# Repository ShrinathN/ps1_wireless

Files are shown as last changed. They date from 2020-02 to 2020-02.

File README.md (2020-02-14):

# Project to turn any original PS1 or PS2 controller wireless using an AVR and a NRF24L01/NRF24L01+ radio

## Hardware

* atmega8a
* NRF24L01+ / NRF24L01
* PS1 / PS2 controller
* 18650 + TP4056 (I'm using an 18650, but you can choose whatever you want)

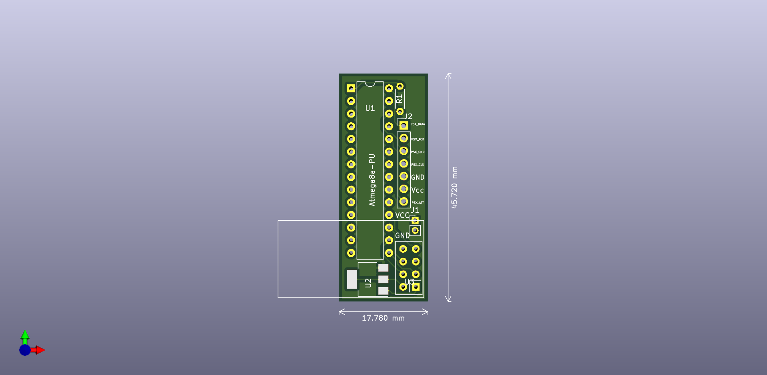
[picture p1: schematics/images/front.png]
Front Image


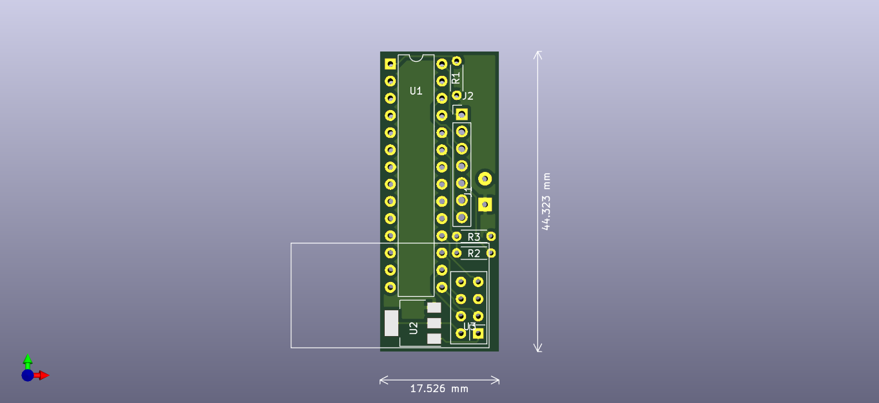
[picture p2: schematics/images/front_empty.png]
Front empty Image


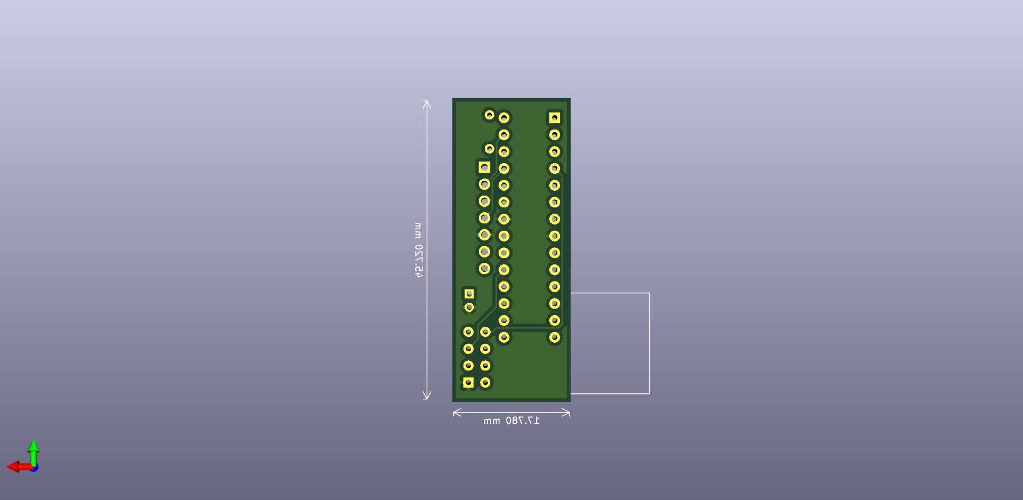
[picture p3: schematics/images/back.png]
Back Image


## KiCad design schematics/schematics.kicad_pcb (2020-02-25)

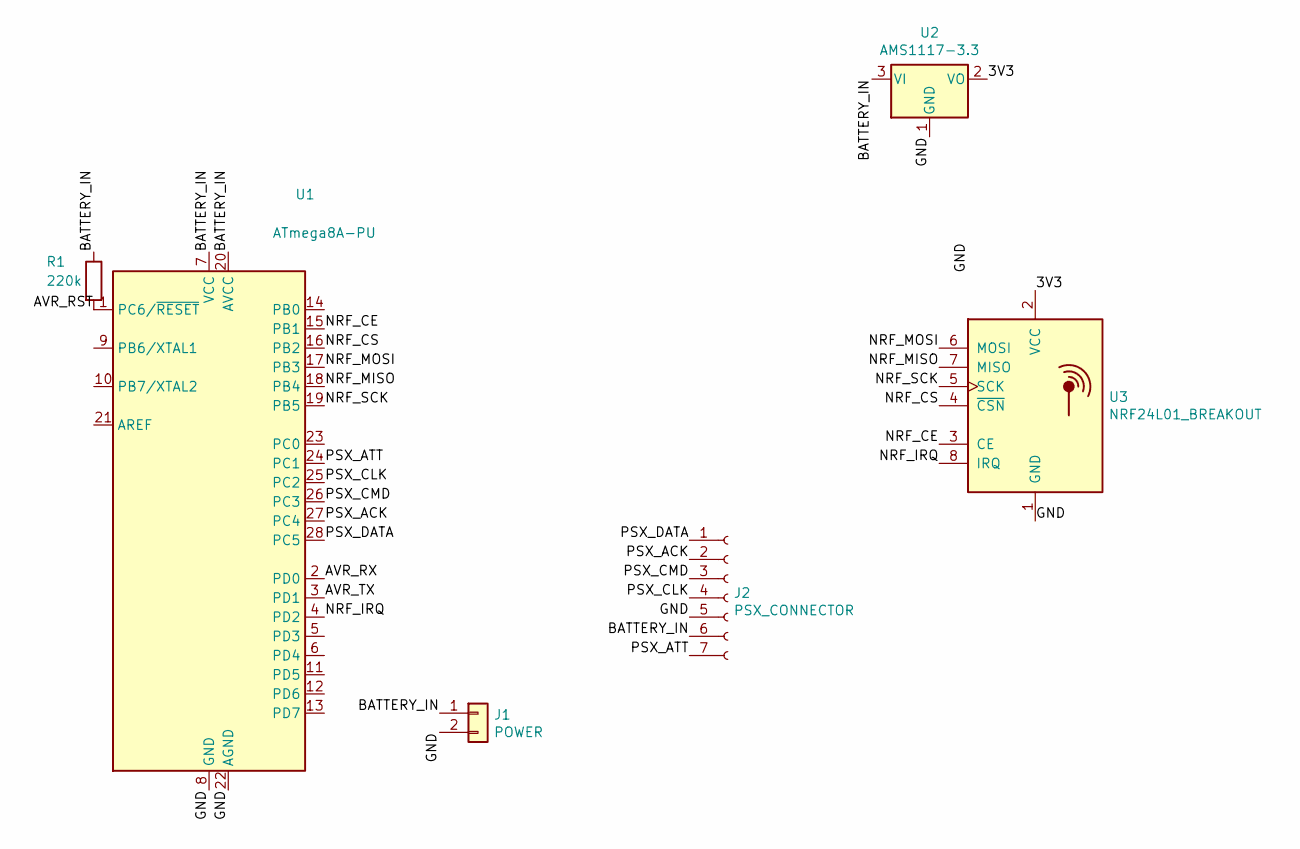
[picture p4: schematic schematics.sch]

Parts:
J1: POWER; PinHeader_1x02_P2.00mm_Vertical
J2: PSX_CONNECTOR; PinHeader_1x07_P2.54mm_Vertical
R1: 220k; R_Axial_DIN0204_L3.6mm_D1.6mm_P5.08mm_Horizontal
U1: ATmega8A-PU; DIP-28_W7.62mm
U2: AMS1117-3.3; SOT-223-3_TabPin2
U3: NRF24L01_BREAKOUT; nRF24L01_Breakout

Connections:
/3V3: U2.2 (VO), U3.2 (VCC)
/AVR_RST: R1.2, U1.1 (PC6/~RESET)
/AVR_RX: U1.2 (PD0)
/AVR_TX: U1.3 (PD1)
/BATTERY_IN: J1.1, J2.6, R1.1, U1.7 (VCC), U1.20 (AVCC), U2.3 (VI)
/GND: J1.2, J2.5, U1.8 (GND), U1.22 (AGND), U2.1 (GND), U3.1 (GND)
/NRF_CE: U1.15 (PB1), U3.3 (CE)
/NRF_CS: U1.16 (PB2), U3.4 (~CSN)
/NRF_IRQ: U1.4 (PD2), U3.8 (IRQ)
/NRF_MISO: U1.18 (PB4), U3.7 (MISO)
/NRF_MOSI: U1.17 (PB3), U3.6 (MOSI)
/NRF_SCK: U1.19 (PB5), U3.5 (SCK)
/PSX_ACK: J2.2, U1.27 (PC4)
/PSX_ATT: J2.7, U1.24 (PC1)
/PSX_CLK: J2.4, U1.25 (PC2)
/PSX_CMD: J2.3, U1.26 (PC3)
/PSX_DATA: J2.1, U1.28 (PC5)

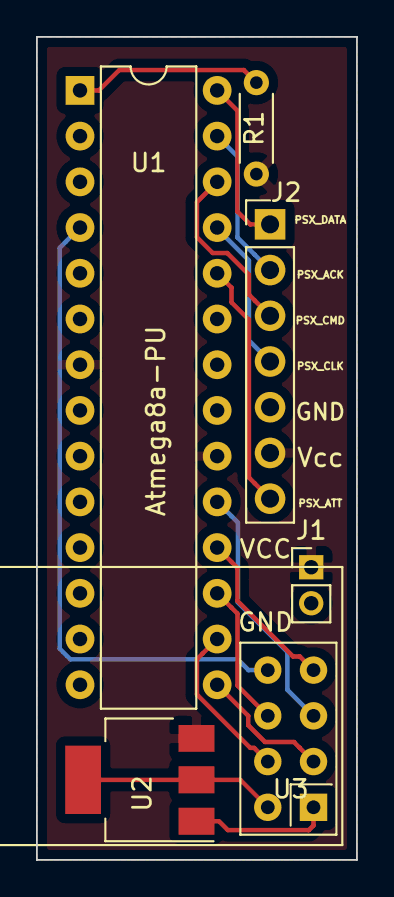
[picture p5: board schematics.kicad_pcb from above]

Board: 2 copper layers, 17.8 x 45.7 mm, 6 parts (0 on the bottom side), 15 nets.

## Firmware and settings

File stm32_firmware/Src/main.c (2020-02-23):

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

/* Includes ------------------------------------------------------------------*/
#include "main.h"
#include "usb_device.h"

/* USER CODE BEGIN Includes */
#include "NRF24L01.h"
/* USER CODE END Includes */

/* USER CODE BEGIN PTD */
extern USBD_HandleTypeDef hUsbDeviceFS;
/* USER CODE END PTD */

/* USER CODE BEGIN PM */
#define LED_OFF HAL_GPIO_WritePin(STATUS_LED_GPIO_Port, STATUS_LED_Pin, GPIO_PIN_SET)
#define LED_ON HAL_GPIO_WritePin(STATUS_LED_GPIO_Port, STATUS_LED_Pin, GPIO_PIN_RESET)
#define LED_TOGGLE HAL_GPIO_TogglePin(STATUS_LED_GPIO_Port, STATUS_LED_Pin)
#define CE_HIGH HAL_GPIO_WritePin(NRF_CE_GPIO_Port, NRF_CE_Pin, GPIO_PIN_SET)
#define CE_LOW HAL_GPIO_WritePin(NRF_CE_GPIO_Port, NRF_CE_Pin, GPIO_PIN_RESET)
/* USER CODE END PM */

SPI_HandleTypeDef hspi1;

void SystemClock_Config(void);
static void MX_GPIO_Init(void);
static void MX_SPI1_Init(void);
/* USER CODE BEGIN 0 */
/*
uint8_t USBD_HID_SendReport(USBD_HandleTypeDef  *pdev,
                            uint8_t *report,
                            uint16_t len)
*/
/* USER CODE END 0 */

/**
  * @brief  The application entry point.
  * @retval int
  */
int main(void)
{
  /* MCU Configuration--------------------------------------------------------*/

  /* Reset of all peripherals, Initializes the Flash interface and the Systick. */
  HAL_Init();

  /* Configure the system clock */
  SystemClock_Config();

  /* Initialize all configured peripherals */
  MX_GPIO_Init();
  MX_SPI1_Init();
  MX_USB_DEVICE_Init();
  /* USER CODE BEGIN 2 */
  HAL_Delay(1000);

  NRF_Init();
  NRF_SetAddressRx((BYTE[]){0x12,0x23,0x34}, 3, 0);
  NRF_WriteRegister(0x11, 3);
  NRF_SetMode(CONFIG_PWR_UP_UP);

  CE_HIGH;
  HAL_Delay(1);

  static BYTE buffer[3];
  BYTE a;
  BYTE b;
  /* USER CODE END 2 */



  /* Infinite loop */
  /* USER CODE BEGIN WHILE */
  while (1)
  {
    /* USER CODE END WHILE */
    /* USER CODE BEGIN 3 */
    while(HAL_GPIO_ReadPin(GPIOA, GPIO_PIN_0) == 1);
    a = NRF_ReadRegister(REG_STATUS);
    NRF_ReadRxFIFO(buffer, 3);
    NRF_WriteRegister(REG_STATUS, 0b01111111 & a);
    buffer[0] ^= 0xff;
    buffer[1] ^= 0xff;

    USBD_HID_SendReport(&hUsbDeviceFS, buffer, 2);
    LED_TOGGLE;
    /* USER CODE END WHILE */

    /* USER CODE BEGIN 3 */
  }
  /* USER CODE END 3 */
}

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


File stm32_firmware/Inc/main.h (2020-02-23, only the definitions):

#define STATUS_LED_Pin GPIO_PIN_13
#define STATUS_LED_GPIO_Port GPIOC
#define NRF_IRQ_Pin GPIO_PIN_0
#define NRF_IRQ_GPIO_Port GPIOA
#define NRF_CSN_Pin GPIO_PIN_3
#define NRF_CSN_GPIO_Port GPIOA
#define NRF_CE_Pin GPIO_PIN_4
#define NRF_CE_GPIO_Port GPIOA
#define NRF_SPI_SCK_Pin GPIO_PIN_5
#define NRF_SPI_SCK_GPIO_Port GPIOA
#define NRF_SPI_MISO_Pin GPIO_PIN_6
#define NRF_SPI_MISO_GPIO_Port GPIOA
#define NRF_SPI_MOSI_Pin GPIO_PIN_7
#define NRF_SPI_MOSI_GPIO_Port GPIOA

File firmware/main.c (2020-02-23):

#include "main.h"

void uart_init()
{
	UCSRB |= (1 << TXEN);
	UCSRC |= (1 << URSEL) |     //selecting UCSRC (NOT UBRRH)
	    (1 << UCSZ0) |      //setting as 8 bits
	    (1 << UCSZ1);
	UBRRL = 103;
}

void uart_send(uint8_t data)
{
	while(!(UCSRA & (1 << UDRE)));
	UDR = data;
}

static const uint8_t psx_poll_request[5] = {0x01,0x42,0,0,0};
static uint8_t recieve_block[5];
static uint8_t old_data[3]; //this is the data being sent
//old_data[0] and old_data[1] are PSX bytes
//old_data[2] is the percentage
static uint16_t loop_run_count;

void main()
{
	DDRB |= 1;
	PORTB &= ~(1);
	uart_init();
	BATTERY_AdcInit();
	PSX_PinsInit();

	//comm system init
	SPI_Init();
	_delay_ms(100);
	NRF_Init();

	NRF_SetAddressTx((uint8_t[]){0x12,0x23,0x34}, 3);
	NRF_SetMode(CONFIG_PWR_UP_UP);
	_delay_ms(2);

	loop_run_count = 0;
	// uart_send(NRF_ReadRegister(REG_CONFIG));
	while(1)
	{
		PSX_TransRecieveBlock((uint8_t *)psx_poll_request, recieve_block, 5);
		if((recieve_block[3] != old_data[0]) || (recieve_block[4] != old_data[1]))
		{
			// PORTB |= 1;
			old_data[0] = recieve_block[3];
			old_data[1] = recieve_block[4];
			NRF_FlushTxBuffer();
			NRF_WriteTxFIFO(old_data, 3);
			// uart_send(NRF_ReadRegister(REG_STATUS));
			// uart_send(NRF_ReadRegister(REG_FIFO_STATUS));
			NRF_Execute();
			NRF_IRQ_WAIT;
			// _delay_ms(10);
			// uart_send(NRF_ReadRegister(REG_STATUS));
			// uart_send(NRF_ReadRegister(REG_FIFO_STATUS));
			//clearing status
			NRF_WriteRegister(REG_STATUS, NRF_ReadRegister(REG_STATUS)  & 0b01111111);
			// _delay_ms(10);
			// PORTB &= ~1;
		}
		if(loop_run_count++ == BATTERY_SAMPLE_TIMER_THRESHOLD)
		{
			loop_run_count = 0;
			old_data[2] = BATTERY_GetPercentage();
		}
	}
}

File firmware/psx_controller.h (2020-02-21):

#ifndef PSX_CONTROLLER_H
#define PSX_CONTROLLER_H
#include "main.h"

//constants
#define PSX_DELAY_CLK_US 10
#define PSX_ATT_DELAY_US 20
#define PSX_INTER_BYTE_DELAY_US 20

//pin definitions
#define PSX_ATT_DDR DDRC
#define PSX_ATT_PORT PORTC
#define PSX_ATT_BIT PC1

#define PSX_CLK_DDR DDRC
#define PSX_CLK_PORT PORTC
#define PSX_CLK_BIT PC2

#define PSX_CMD_DDR DDRC
#define PSX_CMD_PORT PORTC
#define PSX_CMD_BIT PC3

#define PSX_ACK_DDR DDRC
#define PSX_ACK_PORT PORTC
#define PSX_ACK_PIN PINC
#define PSX_ACK_BIT PC4

#define PSX_DATA_DDR DDRC
#define PSX_DATA_PORT PORTC
#define PSX_DATA_PIN PINC
#define PSX_DATA_BIT PC5

//MACROS
#define PSX_CLK_LOW PSX_CLK_PORT &= ~(1 << PSX_CLK_BIT)
#define PSX_CLK_HIGH PSX_CLK_PORT |= (1 << PSX_CLK_BIT)
#define PSX_ATT_LOW PSX_ATT_PORT &= ~(1 << PSX_ATT_BIT)
#define PSX_ATT_HIGH PSX_ATT_PORT |= (1 << PSX_ATT_BIT)
#define PSX_CMD_LOW PSX_CMD_PORT &= ~(1 << PSX_CMD_BIT)
#define PSX_CMD_HIGH PSX_CMD_PORT |= (1 << PSX_CMD_BIT)
#define PSX_READ_DATA ((PSX_DATA_PIN & (1 << PSX_DATA_BIT))?(1):(0))
#define PSX_WAIT_ACK while(PSX_ACK_PIN & (1 << PSX_ACK_BIT))
#define PSX_DELAY_US(x) _delay_us(x)

//different types of controllers
enum
{
	PSX_TYPE_DIGITAL = 0x41,
	PSX_TYPE_NEGCON = 0x23,
	PSX_TYPE_ANALOGUE_RED_LED = 0x73,
	PSX_TYPE_ANALOGUE_GREEN_LED = 0x53
};

//function declarations
void PSX_PinsInit();
void PSX_TransRecieveBlock(uint8_t * transmit_block, uint8_t * recieve_block, uint8_t length);

#endif

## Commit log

2020-02-12 Created schematics
    [schematics.kicad_pcb, schematics.sch]
2020-02-12 Schematics are done
    [schematics-B_Cu.gbl, schematics-B_Mask.gbs, schematics-B_SilkS.gbo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]
2020-02-12 Working on the battery management now
2020-02-15 What an absolute trainwreck. I'm too tired to d o anytinh
2020-02-15 Fixed the unfathomably small problem
    [psx_controller.h]
2020-02-16 Have to make battery reporting work
2020-02-17 Turns out I didn't really need floating point math for this
    [battery.c, battery.h, main.c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]
2020-02-21 Gotta fix IRQ problem
    [NRF24L01.c, NRF24L01.h, main.c]
2020-02-23 AVR firmware works well. STM32 firmware added with USB HID, can be improved.
2020-02-24 Measuring the battery voltage using the internal bandgap voltage input (1.3V), removing the voltage divider
    [schematics.kicad_pcb]
2020-02-25 Updated PCB.
    [schematics-B_Cu.gbl, schematics-B_Mask.gbs, schematics-B_SilkS.gbo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]

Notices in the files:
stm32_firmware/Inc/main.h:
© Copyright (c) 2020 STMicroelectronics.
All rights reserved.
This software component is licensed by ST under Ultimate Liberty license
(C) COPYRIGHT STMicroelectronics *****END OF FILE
